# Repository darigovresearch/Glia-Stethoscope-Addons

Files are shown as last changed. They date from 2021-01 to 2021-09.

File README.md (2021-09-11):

# Glia-Stethoscope-Addons
Repository containing hardware addons for the Glia Stethoscope

## Introduction
This project is to be able to create addons for the off of the [3D printed stethoscope](https://github.com/GliaX/Stethoscope) work done by Glia. The idea is to have a "universal" platform in order to be able to extend the work for any addons that people would want to make for it.

## Notes
None of the content in this repository has been field tested and is for experimental work only

### Philosophy
We will be building any addons under the following philosophy, if you are making an addon please consider taking the following ideas in your design process for your addon to be 
1. Backwards compatible 
    - meaning it should not require any modifications to any currently printed stethoscopes in the wild
2. Under the same license
    - so that people using the addons need only to understand one license
3. Using the same tool set
    - we will be building addons using OpenSCAD so that anybody needing to modify the source only need to know one tool set
4. Low cost
    - any addons should have marginal cost as the stethoscope was designed to be a low cost tool
5. Accessible
    - any addons that require any additional hardware should ideally be able to be sourced anywhere in the world

## Potential Ideas
Not sure what you could add on could go with the stethoscope? Below are some ideas that are worth investigating to see if are possible:
- [ ] Addon to be able to pick up audio of the heartbeat/lungs for remote monitoring/telemedicine or have a machine learning algorithm to pick up key vitals
  - Ideally would also use low cost hardware like headphone microphones 
- [ ] Addon to be able to hold a "reflex hammer" or other items that a medical professional uses for core diagnostics hands free
- [x] [Addon to clip](https://github.com/darigovresearch/Glia-Stethoscope-Addons/blob/main/source_files/stl/addon_otoscope_clip.stl) on the [Glia Otoscope](https://github.com/GliaX/Otoscope) for hands free portability
- [ ] Addon to be able to plug in another Glia stethoscope for two people to monitor at the same time and for teaching purposes

## Contributing
Pull requests, corrections, translations & fixes are welcome. Any contributions must be submitted under the same license as the original piece of work (see below). Take a look at any open issues or submit new ones if there is something that needs to be fixed or added.

Watch our video on how to contribute to open source for a complete overview -> [https://www.youtube.com/watch?v=UWA4wyacY2A](https://www.youtube.com/watch?v=UWA4wyacY2A)

## Print Instructions
In general for prototyping mechanical fits we use ~10% infill and a layer height of 0.3mm in PLA. However if you are using it in a medical setting see the advice on the [source repository](https://github.com/GliaX/Stethoscope) for recommendations on material types, print settings and infill.

## License
Unless otherwise specified, everything in this repository is covered by the following licence:

This project is based off of the work done by Glia on their [3D printed stethoscope](https://github.com/GliaX/Stethoscope). So that any designs are compatible with the source work [license](https://github.com/GliaX/Stethoscope#licensing-notes) we present our work under the TAPR OHL license insofar as it applies.

To see this work in full go to https://github.com/GliaX/Stethoscope

----

<b>
<div align="center">
    The creation, maintenance and continued development of this project is made possible
    <br>
    thanks to our <a href="http://patreon.com/darigovresearch">Patreon</a> and <a href="https://www.darigovresearch.com/donate">Direct</a> supporters!
    <br>
    Consider joining them if you think this project has earned it!
</div>
</b>

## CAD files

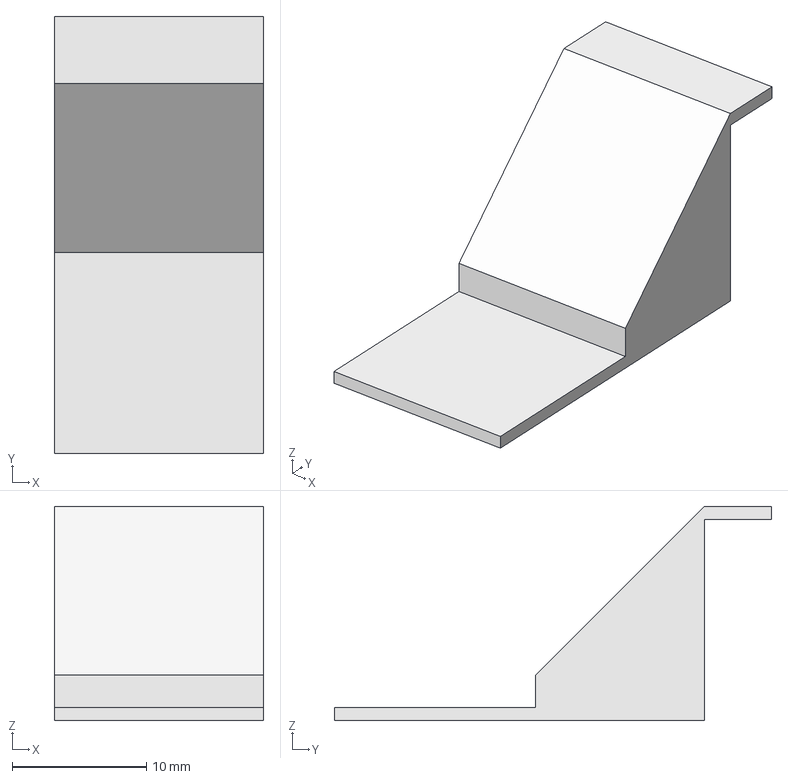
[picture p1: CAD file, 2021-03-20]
source_files/FreeCAD/shelf_mount_cross_bar_shelf.FCStd
15.6 x 32.6 x 16.0 mm

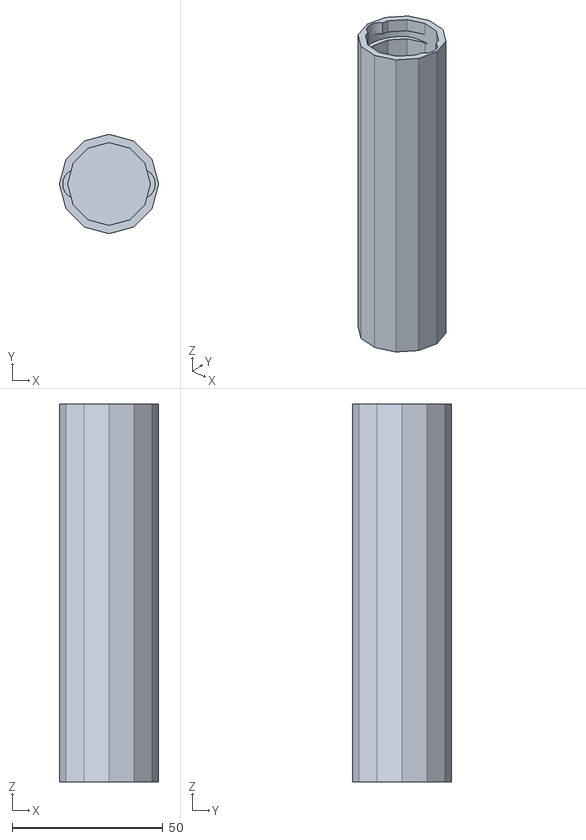
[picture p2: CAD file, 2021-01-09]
source_files/scad/reference/handle_cover.stl
33.0 x 33.0 x 125.5

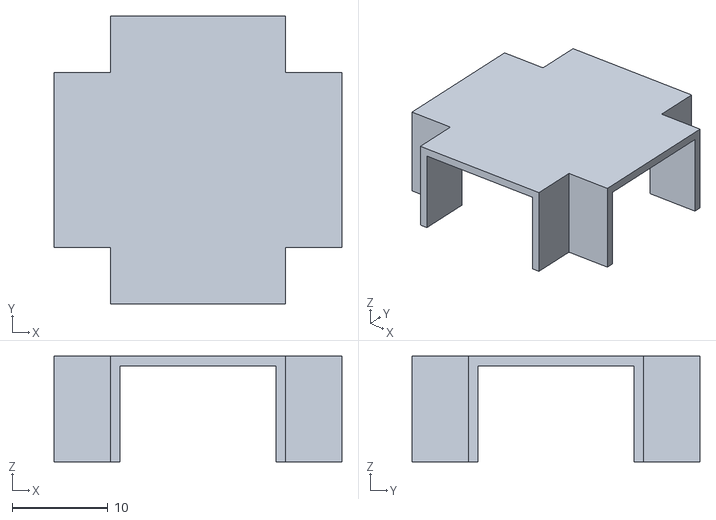
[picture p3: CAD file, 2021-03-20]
source_files/stl/shelf_mount_cross_bar.stl
30.0 x 30.0 x 11.0

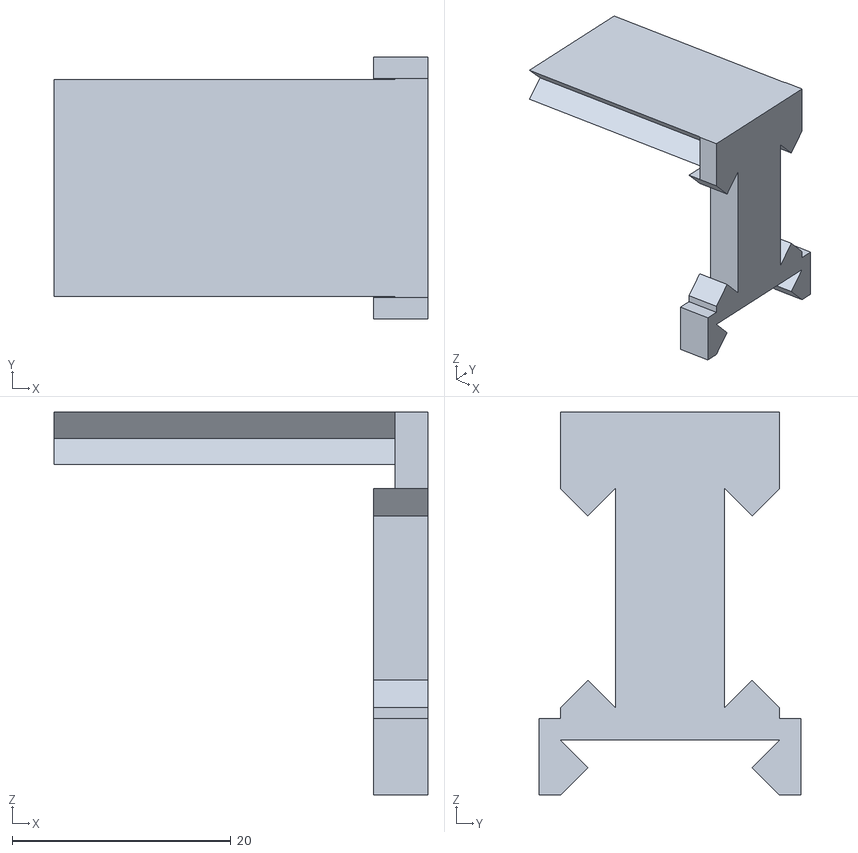
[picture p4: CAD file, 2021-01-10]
source_files/stl/addon_holder.stl
34.2 x 24.0 x 35.0

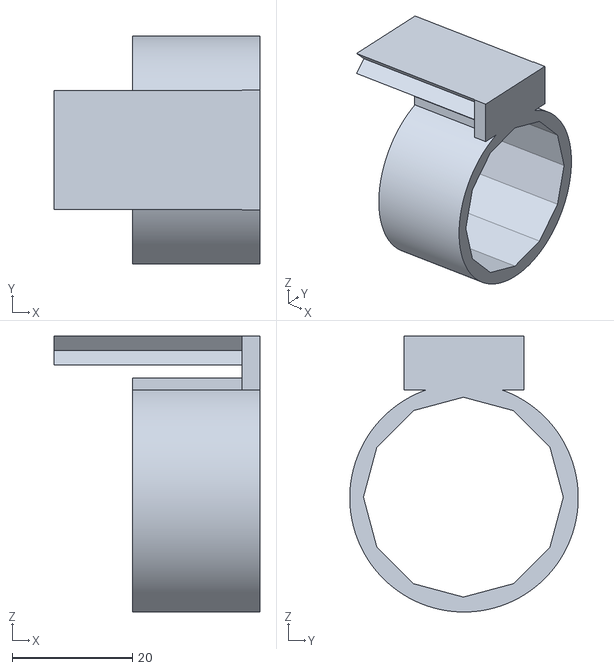
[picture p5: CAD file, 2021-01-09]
source_files/stl/addon_otoscope_clip.stl
34.2 x 38.0 x 45.9

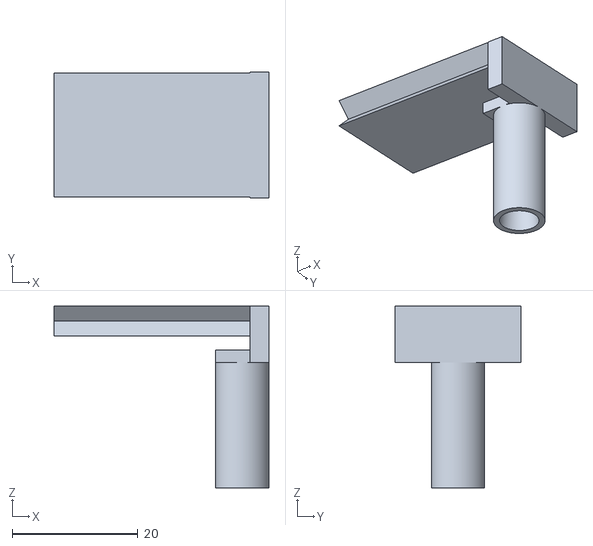
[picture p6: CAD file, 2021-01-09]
source_files/stl/addon_multi_stethoscope.stl
34.2 x 20.0 x 29.0

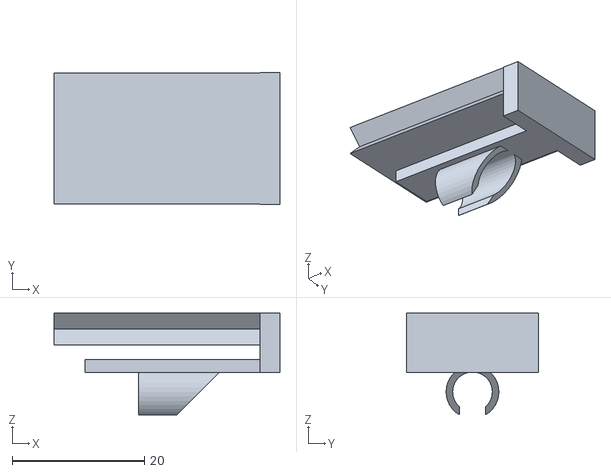
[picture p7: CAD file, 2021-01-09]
source_files/stl/addon_microphone_clip.stl
34.2 x 20.0 x 15.4

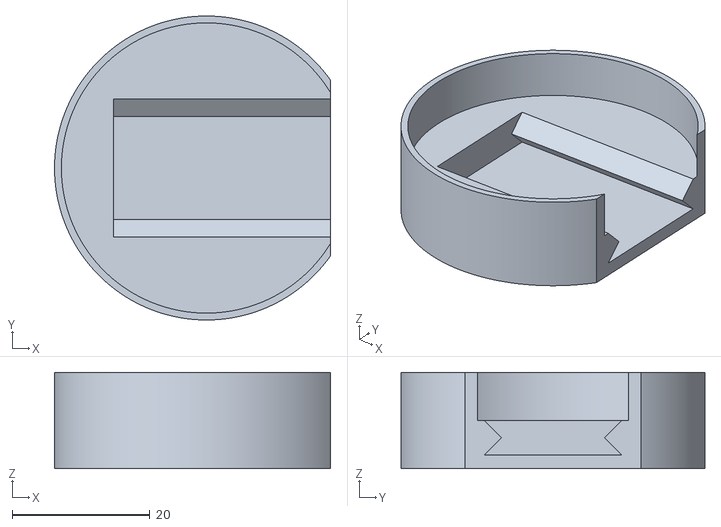
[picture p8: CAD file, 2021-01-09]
source_files/stl/addon_mount.stl
40.1 x 44.1 x 14.0

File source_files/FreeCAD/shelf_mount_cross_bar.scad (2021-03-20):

$tolerence = 0.2;

module cross (a, b, c, depth){
    
    // vertical
    cube([a, c, depth], center=true);

    // horizontal
    cube([c, b, depth], center=true);
}


$wall_thickness = 1;
$depth_thickness = 10;

difference(){
    
    // initial cross
    translate([0, 0, -$depth_thickness/2 + $wall_thickness])
    cross(a=16.2 + 2*$wall_thickness, b=16.2 + 2*$wall_thickness, c=30, depth= $depth_thickness + $wall_thickness);
    
    // cross used to cut away from initial cross
    translate([0, 0, -$depth_thickness/2])
    cross(a=16.2, b=16.2, c=30, depth=$depth_thickness + $wall_thickness);
}

//16.2

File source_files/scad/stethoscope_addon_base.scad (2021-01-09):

$tolerence = 0.2; //Tolerence for mounting parts

//include <stethoscope_addon_mount.scad>;
use <utilities.scad>;

module addon_base(overhang_width, overhang_depth, overhang_height, extension_width, extension_height) {
    
    translate([3, 0, -5/2]) {
       keyway(5 - $tolerence, 20 - $tolerence, 15 - $tolerence, 29 + 3);
    }
    
    // cube that hangs over the mount
    translate([18 + overhang_height/2 + $tolerence, 0, -overhang_depth/2 - $tolerence/2]) {
       cube([overhang_height, overhang_width, overhang_depth], center = true);
    }
    
    // cube that extends down for the addon
    
    //centerlne to calculate new required offset for extension
    $centerline = (overhang_depth - 7)/2;
    translate([18 + $tolerence - extension_height/2, 0, -7 - $centerline - $tolerence/2]) {
       cube([extension_height, extension_width, $centerline*2], center = true);
    }
}

addon_base(20, 9, 3, 8, 26.5);

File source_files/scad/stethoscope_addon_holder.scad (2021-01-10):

//include <stethoscope_addon_mount.scad>;
use <utilities.scad>
use <stethoscope_addon_base.scad>

$tolerence = 0.2; //Tolerence for mounting parts

$clip_height = 21 + $tolerence;

module clip($fn = 45){
    
    
   translate([4.5 +$tolerence, -7.5, -17 - $tolerence/2]) {
       rotate([90, 0, 0]){
        keyway(5, 20, 15, 30 + 3);
       }
   }
   
   translate([4.5 +$tolerence, +7.5, -17 - $tolerence/2]) {
       rotate([90, 0, 0]){
        keyway(5, 20, 15, 30 + 3);
       }
   }
   
   
   translate([4.5 + $tolerence, 0, -32.5 - $tolerence/2]) {
       rotate([0, 0, 0]){
        keyway(5, 20, 15, 30 + 3);
       }
   }
}

// base to mount to the addon
difference () {
    union(){ 
        addon_base(20, 35, 3, 20, 2);
        
        translate([18.5 + $tolerence, 0, -31.4 - $tolerence])
        cube([5, 20 + 4, 7], center=true);
    }
clip();
}

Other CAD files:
source_files/scad/stethoscope_addon_mount.scad
source_files/scad/stethoscope_addon_multi_stethoscope.scad
source_files/scad/stethoscope_multi_port_head.scad
source_files/scad/utilities.scad
source_files/stl/shelf_mount_cross_bar_shelf.stl

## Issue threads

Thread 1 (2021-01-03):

[NEW FEATURE] Addon to clip on the Glia Otoscope for hands free portability

darigovresearch, 2021-01-03:
More details on the Glia Otoscope can be found here - https://github.com/GliaX/Otoscope

darigovresearch, 2021-01-16:
Initial file works well for the standard Glia Otoscope handle

Need to test with a fully assembled Otoscope

darigovresearch, 2021-09-05:
Closing this issue now in favour of #5

Closed 2021-09-05.

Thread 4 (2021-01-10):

[NEW FEATURE] Addon to hold addons

darigovresearch, 2021-01-10:
When having multiple interchangeable addons you need somewhere to store them all

Why not have an addon which can hold other addons when they're not being used!

Could be auto generated so all you need to do is supply the number of addon spaces you need & it will make the addon holder with the relevant amount of slots.

darigovresearch, 2021-05-08:
Commit e593a11796b091863d1f832dfd20f5aa6c615d1e makes an initial manual attempt

darigovresearch, 2021-09-05:
Closing this issue in favour of #6 to make the autogenerated version

Closed 2021-09-05.

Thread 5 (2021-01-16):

Test Otoscope Addon with fully assembled Glia Otoscope

darigovresearch, 2021-01-16:
Relevant to Issue #1

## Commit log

2020-12-27 feat: Adds current addon mount files after initial test fit
    [addon_mount.stl, stethoscope_addon_mount.scad]
2020-12-28 refactor: Adds inline comments to stethoscope_addon_mount.scad
    [stethoscope_addon_mount.scad]
2020-12-28 feat: Adds initial keyway to addon_mount
    [addon_mount.stl, stethoscope_addon_mount.scad]
2020-12-28 refactor: Adjusts spaces between commas & equal signs in stethoscope_addon_mount.scad
    [stethoscope_addon_mount.scad]
2020-12-28 feat: Adds initial addon_microphone_clip pre-test print
    Yet to add the microphone clip, currently it was just to test fit with the addon mount
    [addon_microphone_clip.stl, stethoscope_addon_microphone_clip.scad]
2020-12-28 feat: Adds initial clip to microscope_clip.scad
    [addon_microphone_clip.stl, stethoscope_addon_microphone_clip.scad]
2021-01-02 feat: Adjusts tolerance of addon_mount for tighter fit
    [addon_mount.stl, stethoscope_addon_mount.scad]
2021-01-09 refactor: Adjusts current keyway code to be in a utilities.scad file
    [addon_microphone_clip.stl, addon_mount.stl, stethoscope_addon_microphone_clip.scad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]
2021-01-09 feat: Clones microscope mount to make addon_base to refactor
    [stethoscope_addon_base.scad]
2021-01-09 refactor: Removes clip & keyway code in addon_base.scad
    [stethoscope_addon_base.scad]
2021-01-09 refactor: turns addon_base into a function to pull out the parameters
    [stethoscope_addon_base.scad]
2021-01-09 refactor: Parametrises addon base extension
    [addon_microphone_clip.stl, stethoscope_addon_base.scad, stethoscope_addon_microphone_clip.scad]
2021-01-09 refactor: Adds overhang parameters to addon_base
    [addon_microphone_clip.stl, stethoscope_addon_base.scad, stethoscope_addon_microphone_clip.scad]
2021-01-09 feat: Adds initial multi-stethoscope model to test for issue #2
    [addon_multi_stethoscope.stl, stethoscope_addon_multi_stethoscope.scad]
2021-01-09 feat: Clones microphone clip to make otoscope clip
    [stethoscope_addon_otoscope_clip.scad]
2021-01-09 feat: Adds initial prototype of an otoscope clip for #1
    [addon_otoscope_clip.stl, handle_cover.stl, stethoscope_addon_otoscope_clip.scad]
2021-01-10 feat: Clones otoscope mount to make addon holder
    [stethoscope_addon_holder.scad]
2021-01-10 feat: Adds initial iteration for addon holder #4
    [addon_holder.stl, stethoscope_addon_holder.scad]
2021-03-20 feat: Adds shelf mount & shelf source & .stl files to repo
    [shelf_mount_cross_bar.scad, shelf_mount_cross_bar.stl, shelf_mount_cross_bar_shelf.FCStd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]
2021-09-12 feat: Adds current stethoscope head to reference
    Source being here - https://github.com/GliaX/Stethoscope/blob/master/source_files/scad/stethoscope_head.scad
    [stethoscope_head.scad]
2021-09-12 feat: Clones head to make multi port head to adapt
    Source file - https://github.com/GliaX/Stethoscope/blob/master/source_files/scad/stethoscope_head.scad
    [stethoscope_multi_port_head.scad]
